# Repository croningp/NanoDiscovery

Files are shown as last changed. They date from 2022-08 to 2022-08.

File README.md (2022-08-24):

# Autonomous Intelligent Exploration, DIScovery and Optimisation of Nanomaterials (AI-EDISON)
Software and hardware control of AI-EDISON. The version-specific repository for the paper is available in Zenodo [here](https://zenodo.org/record/6654585). From that version, this repository has been updated from three perspectives below, but no relevant codes/files used in the work have been changed:

1. We corrected some typo errors and updated multiple README.md files as well as statements of license/restrictions for a clearer guidance; 
2. We have added some additional contents which include: a missing [license](Experiments/Software/modularwheelplatform/modularwheel/drivers/pH/DrDAQ/LICENSE.md) of DrDAQ driver locally to this repository (the preivous hyperlink was not valid); the [source codes](Theory/Optimization_targets) to simulate the target spectra for the experimental optimization in the paper.
3. We updated several unused/invalid links, scripts and functions (e.g., several links in [requirement.txt](Experiments/Software/modularwheelplatform/requirements.txt) and the "dense_to_sparse" function (which contains a variable error but was never used) in [dda.py](Theory/PyDScat-GPU/dda.py)) to avoid potential ambiguity.

**Please refer to this repository for general guidance and license information.**


## Experiment

### Hardware construction
The full bill of materials to construct the robot are available [here](Experiments/Hardware).
### Software control requirement
The following software are required to control the robot:
* Python >= 3.6 ([Linux](http://docs.python-guide.org/en/latest/starting/install3/linux/) / [Windows](https://www.python.org/downloads/release/python-363/))
* [Arduino Command Handler](https://github.com/croningp/Arduino-CommandHandler)
* [Arduino Command Tools](https://github.com/croningp/Arduino-CommandTools)
* [pySerial 3.4](https://github.com/pyserial/pyserial/)
* [SerialLabware](https://www.science.org/doi/10.1126/science.abo0058)
* [pycont](https://github.com/croningp/pycont)
* [commanduino](https://github.com/croningp/commanduino)
* [CommanduinoLabware](https://www.science.org/doi/10.1126/science.abo0058)
* [InorganicClusterDiscovery](https://github.com/croningp/InorganicClusterDiscovery)
* [XDL](https://croningroup.gitlab.io/chemputer/xdl/standard/index.html) (with its gitlab link [here](https://gitlab.com/croningroup/chemputer/xdl)) (Note we used XDL 1 in this work. Specifically, [XDL 1.6.0](https://gitlab.com/croningroup/chemputer/xdl/-/tree/v1.6.0) was used to generate the digital signatures of the six AuNPs.)
* [SeaBreeze](https://python-seabreeze.readthedocs.io/en/latest/)
* [PicoTech](https://github.com/picotech/picosdk-python-wrappers)
* [ModularWheelPlatform](Experiments/Software/modularwheelplatform)
* [Nanobot](Experiments/Software/Nanobot)

Go to the corresponidng folders of [ModularWheelPlatform](Experiments/Software/modularwheelplatform) and [Nanobot](Experiments/Software/Nanobot), and use "pip install ." to install these two packages. In ModularWheelPlatform, we used [DrDAQ](https://www.picotech.com/data-logger/drdaq/overview) to measure the pH. In Nanobot, the code is based on [SeaBreeze](https://python-seabreeze.readthedocs.io/en/latest/) from Ocean Optics to control the spectrometers. For the usage of UV-Vis spectrum, the integration time is set (either 0.01 or 0.02 s) to avoid spectral saturation.

<!-- ### Python library -->
<!-- To install all required Python libraries, run the following command: `pip install -r requirements.txt` -->
### Exploration with MAP-Elites
The MAP-Elites algorithm was described in the manuscript and supplementary information. An example of exploring the multiple-peak systems in chemical sapce 2 with pH control is available [here](Experiments/Software).
<!-- ### Optimisation with GS-LS 
The GS-LS algorithm was described in the manuscript and supplementary information. An example of optimizing towards a target spectrum of nanorods is [here](Experiments/Software). -->
### Simulating the target spectra for experimental optimisation
The original codes to simulate the target spectra for Au nanorods/octahedra for the experimental optimisation are [here](Theory/Optimization_targets). See below for more information about the simulation engine PyDScat-GPU.
### Multistep synthesis with directed graph structure
The codes to generate syntehsis/reaction/hardware graph, and control the robot are available [here](Experiments/Graph_Structure).
### The unique digital signatures of the synthesised nanoparticles
The codes to generate the unique digital signatures using XDL are available [here](Experiments/Hash_XDL).
## Theory
### Software requirement
* Python >= 3.6 ([Linux](http://docs.python-guide.org/en/latest/starting/install3/linux/) / [Windows](https://www.python.org/downloads/release/python-363/))
* [numpy](https://numpy.org/)
* [matplotlib](https://matplotlib.org/)
* [Tensorflow >= 2.0](https://www.tensorflow.org/)
* [pathlib](https://docs.python.org/3/library/pathlib.html)
* [fresnel](https://fresnel.readthedocs.io/en/stable/)
* [Mathematica >= 12.0](https://www.wolfram.com/mathematica/)
### PyDScat-GPU
PyDScat-GPU is developed for efficient scaterring simulations with [discrete-dipole approximation](https://en.wikipedia.org/wiki/Discrete_dipole_approximation) method. One example was given below, and see [here](Theory/PyDScat-GPU/) for more details and examples. 
#### Example code
```python
import os
import json
import pathlib
import numpy as np
from dda import DDA

# GPU Device Config
os.environ["CUDA_DEVICE_ORDER"]="PCI_BUS_ID"   
os.environ["CUDA_VISIBLE_DEVICES"]="3"

current_folder_path = pathlib.Path().absolute()

config = {'gpu_device': '/GPU:0',
          'dipole_length': 1,
          'min_wavelength': 0.4,
          'max_wavelength': 0.8,
          'num_wavelengths': 41,
          'ref_medium': 1.333,
          'rotation_steps': 10,
          'folder_path': None,
          'calculate_electricField': True,
          'lattice_constant': 0.41,
          'ref_data': [str(current_folder_path) + '/Au_ref_index.csv',str(current_folder_path) + '/Ag_ref_index.csv'],
          'metals': ["Au","Ag"],
          'dipole_data': str(current_folder_path)+ '/dipole_list.csv',
          "ratio":[1.0, 0.0],
          "method":"homo",
          "custom_ratio_path":None,
          'atom_data':None,
          'lattice_constant': None
        }
config['folder_path'] = str(current_folder_path)
np_dda = DDA(config)
np_dda.run_DDA()
np_dda.plot_spectra()
np.savetxt("Results.csv",np.array(np_dda.C_cross_total)/np.pi/np_dda.c_rad**2,delimiter=",")
```
### Benchmark of MAP-Elites and GS-LS
Both MAP-Elites and GS-LS algorithms were benchmarked in a simulated chemical space using [superellipsoid](https://en.wikipedia.org/wiki/Superellipsoid) as the shape descriptor. The code of creating the discrete dipoe representation of a superellipsoid is [here](Theory/Superellipsoid). We created the set of dipoles by changing the (a,b,c,r,t) parameters of the createDipoles function in the [mathematica notebook](Theory/Superellipsoid/Superellipsoid_Generate_Dipoles.nb) to approximate the specific geometry. 
#### *In silico* exploration using MAP-Elites
The codes to reproduce the results from the in silico exploration of two simulated chemical spaces are [here](Theory/Algorithms). 
#### *In silico* optimisation using GS-LS
The code to reproduce the results from the in silico optimisation is [here](Theory/Algorithms/Simulated_Space_2/1-GS-LS).

## License
The [license](LICENSE) aims to protect the design of the robot in this work for non-commercial usage only. For the codes used in this work, see [here](http://www.chem.gla.ac.uk/cronin/media/license/) for the license information. However, if the licenses listed here are incompatible with the licenses of certain resources that parts of this work are based on, the original licenses of these resources should be used for the relevant parts of this work.

Copyright 2022 The Cronin Group, University of Glasgow.

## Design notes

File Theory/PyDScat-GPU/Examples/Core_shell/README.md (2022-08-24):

dipole_list.csv (name changed), atomList_Octahedron.csv and coordNumList_Octahedron.csv are generated through Nanoparticle_Generator.nb. 
They represent the atomic model for FCC octahedron with an edge length of 20 nm and lattice constant of 0.41 nm.
Then we generated a core-shell structure by setting all the atoms as Ag first, and then change the atoms in the core to be Au later.

The atomic model for the Au core is generated by Nanoparticle_Generator_core.nb for exp1 to exp6, with the edge length from 20 nm to 10 nm.
The lattice constant is consistent with the one above (0.41 nm) and the edge length interval is 2 nm from exp1 to exp6.

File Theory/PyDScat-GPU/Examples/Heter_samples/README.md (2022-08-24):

The dipole list and atomic model are generated with mathematica. It's 20 nm(edge length) octahedron with FCC structure. The lattice constant is 0.41 nm. The file name of dipole set is changed (after created origially) for the DDA simulation.

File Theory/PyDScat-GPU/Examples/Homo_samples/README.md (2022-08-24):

The dipole list and atomic model are generated with mathematica. It's 20 nm(edge length) octahedron with FCC structure. The lattice constant is 0.41 nm. The file name of dipole set is changed (after created origially) for the DDA simulation. The atomic model is not really used in this example so are deleted in this batch of experiments.

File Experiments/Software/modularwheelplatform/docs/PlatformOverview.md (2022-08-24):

# Platform
The following is a generalised guide on how to structure your project. The structure of a project follows a standard as set [here.](http://datalore.chem.gla.ac.uk/GAK/PlatformTemplate) This is a base template structure that can be added to/modified to fit your project's specific needs.

# Basic Platform Structure
platformstructure

# Requirements
* [Commanduino](https://github.com/croningp/commanduino)
* [Arduino Command Handler](https://github.com/croningp/Arduino-CommandHandler)
* [Arduino Command Tools](https://github.com/croningp/Arduino-CommandTools)
* [PyCont](https://github.com/croningp/pycont) (If using Tricontinent Pumps)

# Project Folder
Holds all the information necessary to run the platform. It is split into two main folders: **Hardware** and **Software**

## **Hardware**
Holds all the files necessary for the building of this platform. Here, you can add STL files for 3D printed parts, links to building materials such as cross-beams, motors, Arduino kits, etc., amongst other items necessary for the construction of your platform. This repository comes fully equipped with all the 3D files necessary for construction and links to purchasing said building materials.

## **Software** 
Holds all the software necessary for operating your platform. A hierarchial structure is adopted here to maximise modularity, allowing additional modules to be introduced/removed as and when required. Firmware and Utilities folders should also be included to hold the Arduino code and general purpose fuctions respectively. The project structure is as follows:
```
Base Layer -> Operational Layer -> Managerial Layer
```
## Base Layer
This is the lowest level of the platform which implements the base functionality of the platform. That being, no specific operations would be conducted in these scripts, just basic setup and low-level functions. Examples would be setting up Tricont pumps, initialising a UV spectrometer or pH probe, setting up a camera, etc. See examples below:

### **PyCont Pump Base Layer**
This script simply sets up the Tricont pump controller using PyCont and sets all pumps to 0. The controller can then be called upon from an Operations script to give access to the pumps.  
For more information on PyCont, click [here](https://github.com/croningp/pycont).
```python
# Base Layer: PUMPS

import os
import inspect
import logging
import json

logging.basicConfig(level=logging.INFO)

HERE = os.path.dirname(os.path.abspath(inspect.getfile(inspect.currentframe())))
from pycont.controller import MultiPumpController

config_path = os.path.join(HERE, "pycont_config.json")
controller = MultiPumpController.from_configfle(config_path)

with open(config_path) as f:
    config = json.load(f)

controller.smart_initialize()

pumps = controller.get_pumps(controller.pumps)
for pump in pumps:
    pump.go_to_volume(0)
```

### **Commanduino Device Base Layer**
This script sets up Commanduino for any Arduino device, allowing you to access any device currently attached to it that is listed in its commanduino config file (operations/configs folder).  
For more information on how to use Commanduino, click [here](https://github.com/croningp/commanduino).
```python
import os
import sys
import json
import time
import inspect

from commanduino import CommandManager

HERE = os.path.dirname(os.path.abspath(inspect.getfile(inspect.currentframe())))

root_path = os.path.join(HERE, "..")
sys.path.append(root_path)

from utils import json_utils

""" CONSTANTS """
DEVICES = "devices"

class CoreDevice(object):
    """
    Class representing a core Commanduino system.
    Allows access to the modules attached

    Args:
        config (str): path to the Commanduino config file
    """
    def __init__(self, config):
        self.mgr = CommandManager.from_configfile(config)
        self.config = json_utils.read_json(config)

    def valid_device(self, dev_name):
        """
        Checks if the given device name is present within the config

        Args:
            dev_name (str): name of the device
        
        Returns:
            valid (bool): If the device is present or not
        """
        return dev_name in self.config[DEVICES].keys()

    def get_device_attribute(self, dev_name):
        """
        Gets the device attribute from CommandManager

        Args:
            dev_name (str): Name of the device

        Returns:
            device (CommandDevice): Device instance in the CommandManager

        Raises:
            AttributeError: The device is not in the CommandManager
        """
        if self.valid_device(dev_name):
            try:
                return getattr(self.mgr, dev_name)
            except AttributeError:
                print("No device named {0} in the manager!\nBailing out!".format(dev_name))
                sys.exit(-1)
        else:
            print("Invalid device name: {0}".format(dev_name))
            sys.exit(-1)

```

## Operational Layer
The operational layer is responsible for implementing all the functions specific to your platform. This takes a base layer component and adds a control script on top, allowing access to the hardware to perform the desired function.  
An example would be setting up a cleaning routine for pumps, dispensing reagents from pumps, turning the Geneva Wheel, raising and lowering modular drivers on the wheel etc.  
See below:

### **Example: Geneva Wheel Control Operations**
This example highlights using the Commanduino Core Base Layer and incorporating it into an operational layer control script for a Geneva Wheel. By using the base layer methods, we can get access to all the devices attached and write functions to perform specific tasks. In this case, turning the wheel, moving modular drivers and runing peristaltic pumps.
```python
import os
import sys
import time
import inspect

HERE = os.path.dirname(os.path.abspath(inspect.getfile(inspect.currentframe())))
root_path = os.path.join(HERE, "..")
sys.path.append(root_path)

from base_layer.commanduino_setup.core_device import CoreDevice

""" CONSTANTS """
WHEEL_NAME = "wheel"
FULL_WHEEL_TURN = 6400
PUMP_INCREMENT = 8000
MODULE_LOWER = -39000

class WheelControl(CoreDevice):
    """
    Class for controlling a Geneva Wheel system
    Contains methods for rotation, modular drivers, pumps, etc.
    Assumes the user has at least one Geneva wheel, one modular driver, and one peristaltic
    pump attached to their rig.

    Inherits:
        CoreDevice: Base Commanduino Device

    Args:
        config (str): Path to the config
    """
    def __init__(self, config):
        super().__init__(self, config)

    def turn_wheel(self, n_turns, wait=True):
        """
        Turns the Geneva Wheel n_turns times

        Args:
            n_turns (int): Number of turns
        """
        drive_wheel = self.get_device_attribute(WHEEL_NAME)
        for _ in range(n_turns):
            drive_wheel.move(FULL_WHEEL_TURN, wait=wait)

    def move_module(self, mod_name, pos, wait=True):
        """
        Moves the modular driver to a set position

        Args:
            mod_name (str): Name of the module
            pos (int/float): Number of steps to move
            wait (bool): Wait for the device to be idle, default set to True
        """
        module = self.get_device_attribute(mod_name)
        module.move(-pos, wait=wait) # -ve due to inverted direction

    def lower_module(self, mod_name, wait=True):
        """
        Lowers the modular driver

        Args:
            mod_name (str): Name of the modular driver
            wait (bool): Wait for the device to be idle, default set to true
        """
        self.move_module(mod_name, MODULE_LOWER, wait=wait)

    def home_module(self, mod_name, wait=True):
        """
        Brings the module back to its home position

        Args:
            mod_name (str): Name of the module
            wait (bool): Wait for the device to be idle, default set to true
        """
        module = self.get_device_attribute(mod_name)
        module.home(wait=wait)

    def run_peri_pump(self, pump_name, num_secs):
        """
        Runs a peristaltic pump for num_secs time

        Args:
            pump_name (str): Name of the pump
            num_secs (int/float): Number of seconds to run for
        """
        pump = self.get_device_attribute(pump_name)
        curr_time = time.time()
        while time.time() < (curr_time + num_secs):
            pump.move(PUMP_INCREMENT)    

```

## Managerial Layer
The Managerial Layer is responsible for consolidating all required operational layer modules into a single, easily accessible script. This script can then be called by an experimental run script to give you access to all the functions.  
By doing so, wrapper functions can be implemented that encompass an entire operation e.g. cleaning. Other manager functions can also be implemented. Example function below:
```python
# manager.py
def clean_routine(self):
    self.wheel_control.lower_module()
    self.pump_control.empty_vessel()
    self.pump_control.clean()
    self.wheel_control.home_module()
    self.wheel_control.turn_wheel()
```
Skeletal example of a manager.py file:
```python
import os
import sys
import inspect

HERE = os.path.dirname(os.path.abspath(inspect.getfile(inspect.currentframe())))
root_path = os.path.join(HERE, "..")
sys.path.append(root_path)

""" Operations Modules """
from operations.tricont_control import TricontControl
from operations.wheel_control import WheelControl
# Add more as required

class Manager(object):
    """
    Class representing a manager which governs the entire platform
    Wrapper around certain operations for the platform and general management
    """
    def __init__(self):
        self.pump_control = TricontControl()
        self.wheel_control = WheelControl()
        # Add more as required

    """
    Add general managerial functions here 
    """

    """
    Add wrappers to operational functions here
    """

```

## Firmware
The firmware folder is where all Arduino and microcontroller code should be stored. For Arduino code to be used with Commanduino, please see the [Arduino Command Handler](https://github.com/croningp/Arduino-CommandHandler) and [Arduino Command Tools](https://github.com/croningp/Arduino-CommandTools) repositories for installation instructions and demos.

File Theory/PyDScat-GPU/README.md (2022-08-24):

# Config file for PyDScat-GPU simulation
The major part was written in Python. The config file defines the necessary information for simulation. There're several parameters in the config file (a dictionary and usually stored as a json file) and see the information below for different parameters:
1. 'gpu_device': '/GPU:0',
- defines the GPU device to be used
2. 'dipole_length': 1,
- defines the length of dipole in nanometer
3. 'min_wavelength': 0.4, 
- defines the lowest wavelength for spectrum in micrometer
4. 'max_wavelength': 0.8, 
- defines the highest wavelength for spectrum in micrometer
5. 'num_wavelengths': 41, 
- defines the number of linear interval between lowest and highest wavelength
6. 'ref_medium': 1.333, 
- defines the medium of the simulation
7. 'rotation_steps': 10, 
- defines the average number of orientations for every solid angle
8. 'folder_path': None, 
- defines the folder path where we store the data (still in test so some data may store in the current folder)
9. 'calculate_electricField': False, 
- defines if we will calculate the local electric field
10. 'metals': ["Au","Ag"], 
- defines the metallic components in the nanoparticles
11. 'ref_data': [str(current_folder_path) + '/Au_ref_index.csv',str(current_folder_path) + '/Ag_ref_index.csv'],
-  defines the refractive index for components respectively. Keep the sequence of paths consistent with those in metals.
12. 'dipole_data': str(current_folder_path)+'/Core_shell' + '/dipole_list.csv',
- defines the position of dipoles. Always integer. 
13. "method":"heter_atomic",
- defines the method for the simulation. It can be "homo", "heter_atomic" or "heter_custom"
14. "ratio":None,
- has to be defined for method "homo", else not required. A list object recording the percentages of different components of the homogenous nanoparticle. The summation should be 1. 
15. "custom_ratio_path":None
- has to be defined for method "heter_custom", else not required. Path to the csv file storing the custom component percentages for dipoles. After reading in the csv file, we should have a n by N array, where n is the metallic component number and N is the dipole number.
16. 'atom_data': str(current_folder_path)+'/Core_shell' + exp_index + '/atomList_Octahedron.csv',
- has to be defined for method "heter_atomic", else not required. It defines the path for the positions of atoms. Always normarlized to lattice unit. 
17. 'lattice_constant': 0.41
- has to be defined for method "heter_atomic", else not required. It defines the lattice constant for an atomic model

[Mathematica >= 12.0](https://www.wolfram.com/mathematica/) was used to generate dipoles or create meshes to calculate the electric field distribution if 'calculate_electricField' is True. For this calculation, the dipole length and the lattice constant should be set in [NanoparticleProperties.wl](NanoparticleProperties.wl) accordingly. The path in [dipole_analysis.wls](dipole_analysis.wls) should be changed accordingly to load the package.

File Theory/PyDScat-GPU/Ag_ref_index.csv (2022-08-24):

Wavelength, µm | real | image
0.1879 | 1.07 | 1.212
0.1916 | 1.1 | 1.232
0.1953 | 1.12 | 1.255
0.1993 | 1.14 | 1.277
0.2033 | 1.15 | 1.296
0.2073 | 1.18 | 1.312
0.2119 | 1.2 | 1.325
0.2164 | 1.22 | 1.336
0.2214 | 1.25 | 1.342
0.2262 | 1.26 | 1.344
0.2313 | 1.28 | 1.357
0.2371 | 1.28 | 1.367
0.2426 | 1.3 | 1.378
0.249 | 1.31 | 1.389
0.2551 | 1.33 | 1.393
0.2616 | 1.35 | 1.387
0.2689 | 1.38 | 1.372
0.2761 | 1.41 | 1.331
0.2844 | 1.41 | 1.264
0.2924 | 1.39 | 1.161
0.3009 | 1.34 | 0.964
0.3107 | 1.13 | 0.616
0.3204 | 0.81 | 0.392
0.3315 | 0.17 | 0.829
0.3425 | 0.14 | 1.142
0.3542 | 0.1 | 1.419
0.3679 | 0.07 | 1.657
0.3815 | 0.05 | 1.864
0.3974 | 0.05 | 2.07
0.4133 | 0.05 | 2.275
0.4305 | 0.04 | 2.462
0.4509 | 0.04 | 2.657
0.4714 | 0.05 | 2.869
0.4959 | 0.05 | 3.093
0.5209 | 0.05 | 3.324
0.5486 | 0.06 | 3.586
0.5821 | 0.05 | 3.858
0.6168 | 0.06 | 4.152
0.6595 | 0.05 | 4.483
0.7045 | 0.04 | 4.838
0.756 | 0.03 | 5.242
0.8211 | 0.04 | 5.727
0.892 | 0.04 | 6.312
0.984 | 0.04 | 6.992
1.088 | 0.04 | 7.795
1.216 | 0.09 | 8.828
1.393 | 0.13 | 10.1
1.61 | 0.15 | 11.85
1.937 | 0.24 | 14.08

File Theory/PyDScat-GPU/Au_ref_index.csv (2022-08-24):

Wavelength, µm | real | image
0.1879 | 1.28 | 1.188
0.1916 | 1.32 | 1.203
0.1953 | 1.34 | 1.226
0.1993 | 1.33 | 1.251
0.2033 | 1.33 | 1.277
0.2073 | 1.3 | 1.304
0.2119 | 1.3 | 1.35
0.2164 | 1.3 | 1.387
0.2214 | 1.3 | 1.427
0.2262 | 1.31 | 1.46
0.2313 | 1.3 | 1.497
0.2371 | 1.32 | 1.536
0.2426 | 1.32 | 1.577
0.249 | 1.33 | 1.631
0.2551 | 1.33 | 1.688
0.2616 | 1.35 | 1.749
0.2689 | 1.38 | 1.803
0.2761 | 1.43 | 1.847
0.2844 | 1.47 | 1.869
0.2924 | 1.49 | 1.878
0.3009 | 1.53 | 1.889
0.3107 | 1.53 | 1.893
0.3204 | 1.54 | 1.898
0.3315 | 1.48 | 1.883
0.3425 | 1.48 | 1.871
0.3542 | 1.5 | 1.866
0.3679 | 1.48 | 1.895
0.3815 | 1.46 | 1.933
0.3974 | 1.47 | 1.952
0.4133 | 1.46 | 1.958
0.4305 | 1.45 | 1.948
0.4509 | 1.38 | 1.914
0.4714 | 1.31 | 1.849
0.4959 | 1.04 | 1.833
0.5209 | 0.62 | 2.081
0.5486 | 0.43 | 2.455
0.5821 | 0.29 | 2.863
0.6168 | 0.21 | 3.272
0.6595 | 0.14 | 3.697
0.7045 | 0.13 | 4.103
0.756 | 0.14 | 4.542
0.8211 | 0.16 | 5.083
0.892 | 0.17 | 5.663
0.984 | 0.22 | 6.35
1.088 | 0.27 | 7.15
1.216 | 0.35 | 8.145
1.393 | 0.43 | 9.519
1.61 | 0.56 | 11.21
1.937 | 0.92 | 13.78

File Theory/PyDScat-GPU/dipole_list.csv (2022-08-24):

-1.399999999999999467e+01 | 0.000000000000000000e+00 | 0.000000000000000000e+00
-1.299999999999999822e+01 | -9.999999999999964473e-01 | 0.000000000000000000e+00
-1.299999999999999822e+01 | 0.000000000000000000e+00 | -9.999999999999964473e-01
-1.299999999999999822e+01 | 0.000000000000000000e+00 | 0.000000000000000000e+00
-1.299999999999999822e+01 | 0.000000000000000000e+00 | 1.000000000000005329e+00
-1.299999999999999822e+01 | 1.000000000000005329e+00 | 0.000000000000000000e+00
-1.199999999999999289e+01 | -1.999999999999992895e+00 | 0.000000000000000000e+00
-1.199999999999999289e+01 | -9.999999999999964473e-01 | -9.999999999999964473e-01
-1.199999999999999289e+01 | -9.999999999999964473e-01 | 0.000000000000000000e+00
-1.199999999999999289e+01 | -9.999999999999964473e-01 | 1.000000000000005329e+00
-1.199999999999999289e+01 | 0.000000000000000000e+00 | -1.999999999999992895e+00
-1.199999999999999289e+01 | 0.000000000000000000e+00 | -9.999999999999964473e-01
-1.199999999999999289e+01 | 0.000000000000000000e+00 | 0.000000000000000000e+00
-1.199999999999999289e+01 | 0.000000000000000000e+00 | 1.000000000000005329e+00
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

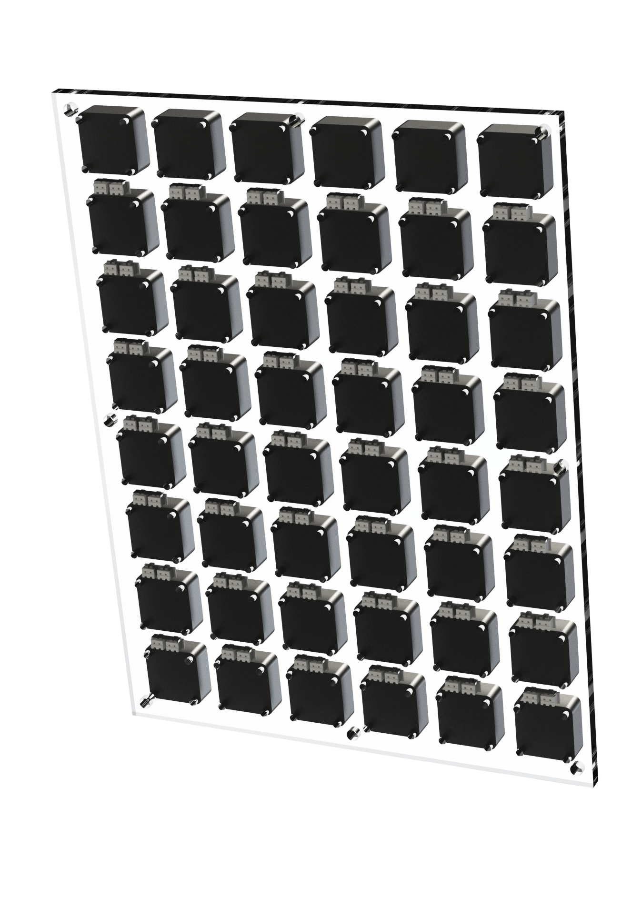
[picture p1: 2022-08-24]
Experiments/Software/modularwheelplatform/docs/hardware/StirringRingPCB/renders/plate_bottom_view.png

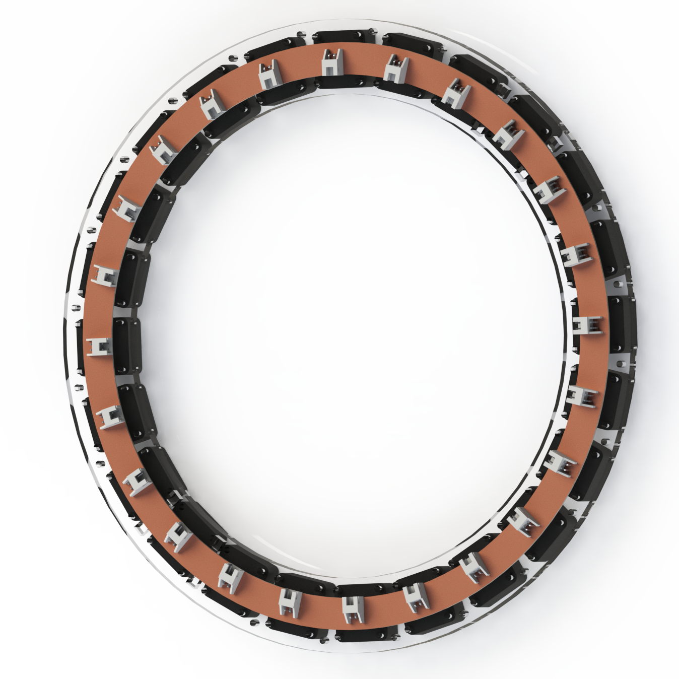
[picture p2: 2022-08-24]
Experiments/Software/modularwheelplatform/docs/hardware/StirringRingPCB/renders/ring_bottom_view.png

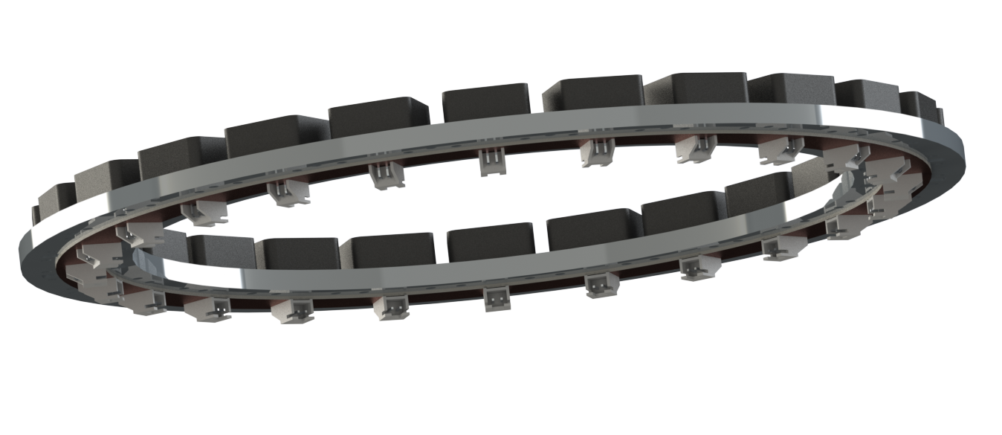
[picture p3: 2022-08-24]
Experiments/Software/modularwheelplatform/docs/hardware/StirringRingPCB/renders/ring_side_view.png

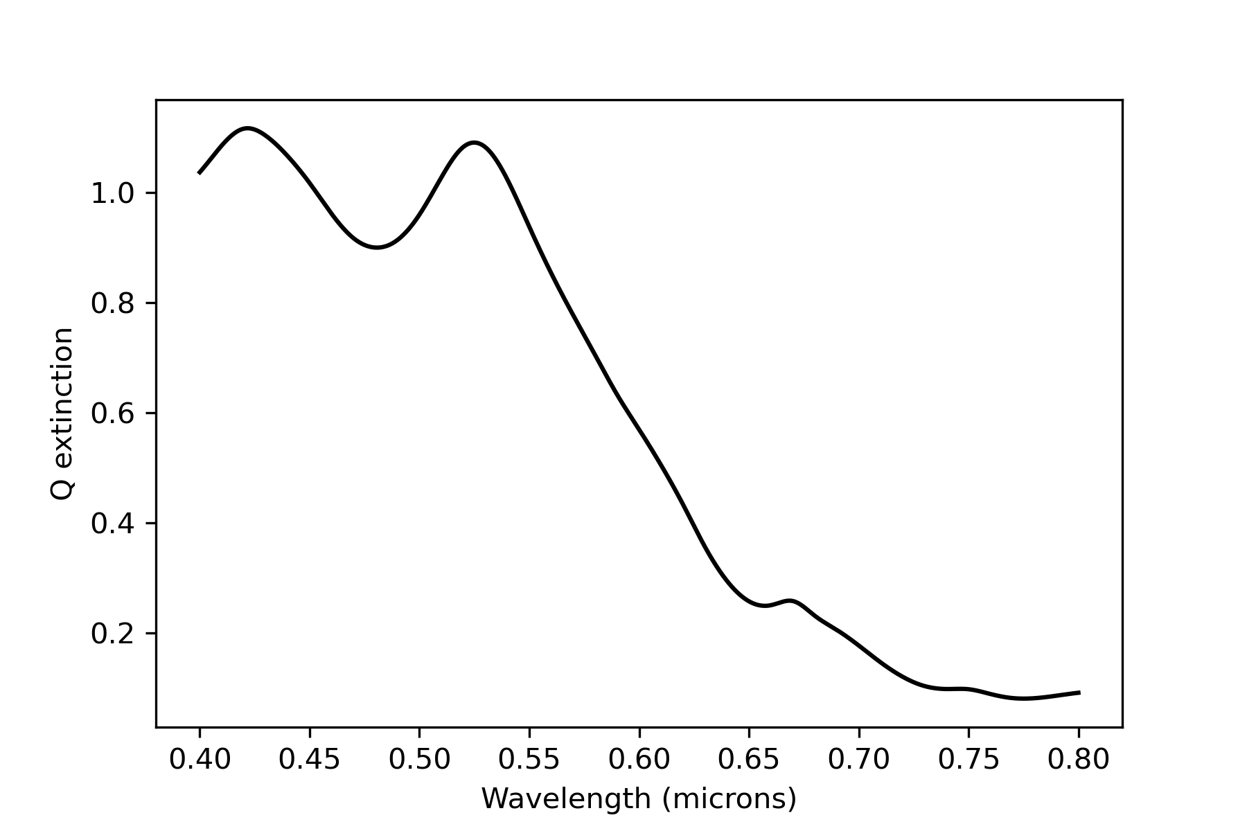
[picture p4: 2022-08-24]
Theory/PyDScat-GPU/Examples/Core_shell/exp2/UV_Vis.png

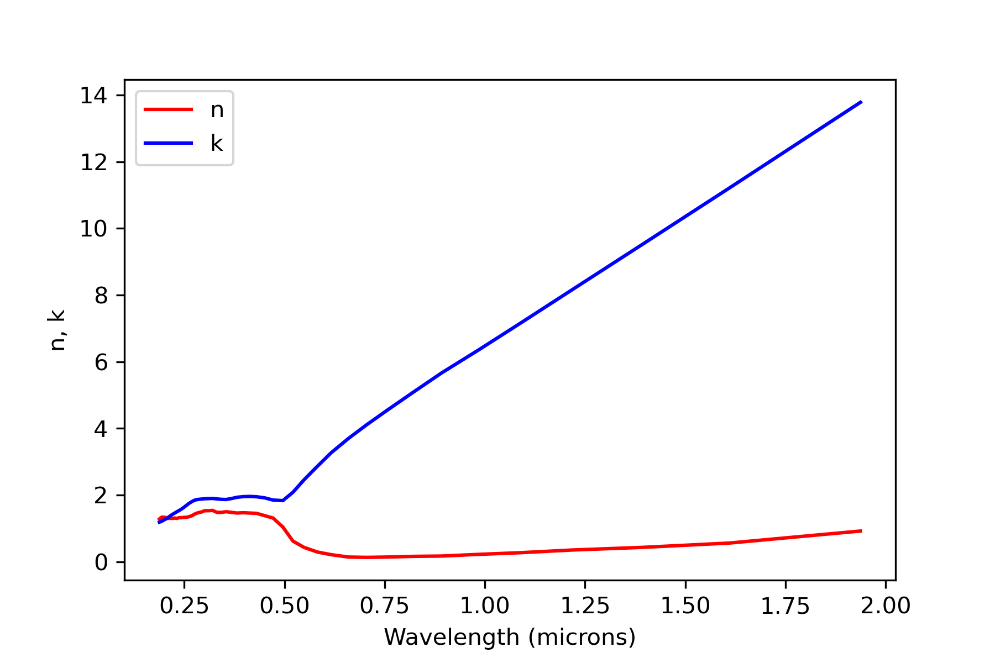
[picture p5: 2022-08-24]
Theory/PyDScat-GPU/Examples/Core_shell/exp5/Au_ref_index.png

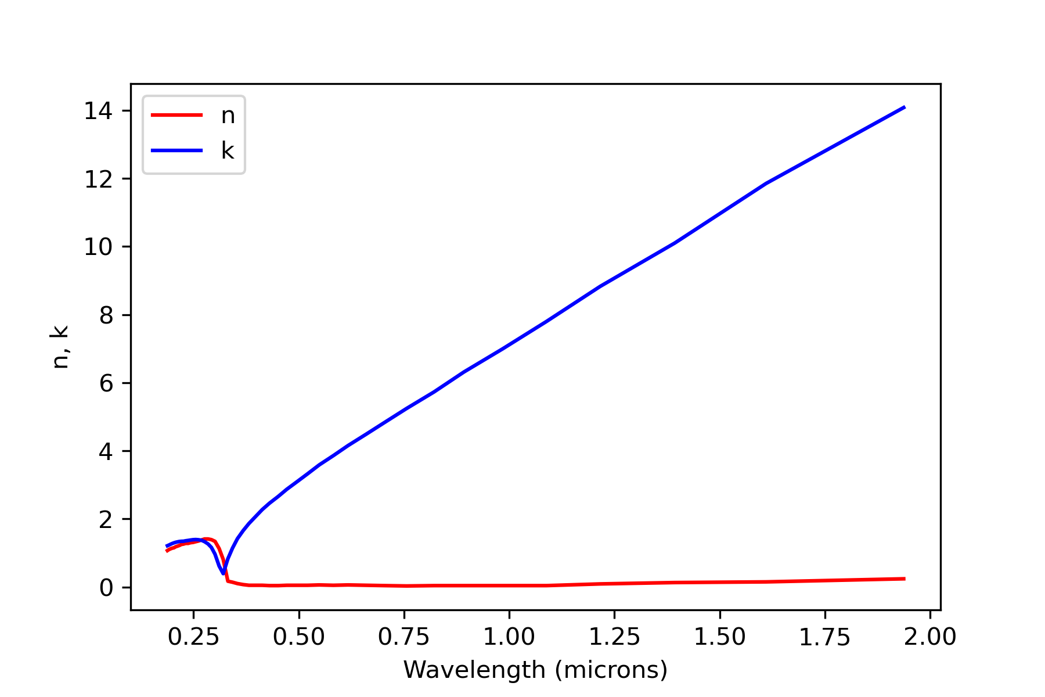
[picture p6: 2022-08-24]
Theory/PyDScat-GPU/Examples/Heter_samples/exp3/Ag_ref_index.png

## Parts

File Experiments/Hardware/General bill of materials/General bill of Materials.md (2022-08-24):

# Bill of Materials

This page contains a brief description of and links for the commercially available parts needed to construct this platform   

# Base components for chemical reaction module

* Structural: V-slot aluminium [profile](http://ooznest.co.uk/V-Slot/Linear-Rails/V-Slot-Linear-Rail-2020mm):
  - 310 mm x 4
  - 350 mm x 4
  - 135 mm x 4
* Structural: 60 (each) M5 x 8mm and 6mm [screws](http://ooznest.co.uk/Low-Profile-M5-Bolts?search=M5) with accompanying 120 [drop-in tee nuts](http://ooznest.co.uk/Drop-In-Tee-Nuts?search=drop) you will have spares
* Structural: 16 x Universal (single) L-[bracket](http://ooznest.co.uk/V-Slot/Brackets/Universal-L-Brackets)
* Structural: [Acrylic](http://www.acrylic-online.co.uk/) sheets 4mm and 6 mm (600 x 500mm minimum) x 1
* Structural: Assorted 3D printed [parts](https://github.com/croningp/NanomatDiscovery/tree/master/Experiments/Hardware/Modular%20wheel/Prints)
* Structural: Assorted M3 x 12/16/20/30mm [screws](https://www.accu.co.uk/en/64-low-head-cap-screws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) and [nuts](https://www.accu.co.uk/en/44-thin-hexagon-nuts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)
* Structural: Slot [cover](https://ooznest.co.uk/product/slot-cover/) for organising cables and tubes
* Electronic: Arduino mega 2560 and [RAMPS](https://ooznest.co.uk/product/ramps-14-controller-board/) 1.4 with a [DRV8825](https://ooznest.co.uk/product/drv8825-stepper-motor-driver/) driver for each motor you intend to use. The options for the Arduino is included in the drop down menu options x 1
* Electronic: 25 x 25 x 10 mm DC [fans](http://ooznest.co.uk/12V-DC-25mm-Fan?search=25mm). 24 for the platform stirring ring and 48 for the stirring mantle. For each fan you will need a JST housing pair, [male](https://uk.rs-online.com/web/p/pcb-headers/8201582/) and [female](https://uk.rs-online.com/web/p/pcb-connector-housings/8201611/), using these JST [crimps](https://uk.rs-online.com/web/p/pcb-connector-contacts/8201529) for powering the stirring fans.
* Electronic: Crimping [tool](https://www.crimpingtools.com/products/iwiss-xh2-54-3-96-ph2-0-px-kk254-jst-molex-dupont-d-sub-terminal-crimping-tool-sn-01bm-rachet-crimper-awg28-20-0-08-0-5mm) specific to the fan assemblies 
* Electronic: For simple electrical connections eg between the power supple and RAMPs board any crimp/ crimp housing conncetion can be used. We use simple Molex housings for crimps: [male](https://uk.rs-online.com/web/p/pcb-connector-housings/4841811/) and [female](https://uk.rs-online.com/web/p/pcb-connector-housings/4841748/) with accompanying crimps: [male](https://uk.rs-online.com/web/p/pcb-connector-contacts/6706316/) and [female](https://uk.rs-online.com/web/p/pcb-connector-contacts/6706307/)
* Electronic: Corsair SF450 [power supply](https://www.amazon.co.uk/Corsair-SF450-Fully-Modular-Supply/dp/B01CR5XJR6) x 1
* Electronic: Nema17 stepper x 1 [motor](https://www.omc-stepperonline.com/nema-17-bipolar-45ncm-64oz-in-2a-42x42x40mm-4-wires-w-1m-cable-and-connector.html) with accompanying Pololu aluminium mounting [hub](https://www.pololu.com/product/1998). This part joins the drive wheel to the stepper motor shaft x1
* Electronic: 4-wire Molex [female](https://uk.rs-online.com/web/p/pcb-connector-contacts/0467598/) crimps and [housings](https://uk.rs-online.com/web/p/pcb-connector-housings/6795375/) for Stepper motors, both pumps and drive wheel.  
* Electronic: Any 2 and 4 way crimp housings. It matters that the crimps match the plastic housings you chose, beyond that many types can be used.
* Electronic: Stepper motor to RAMP connection [housings](https://uk.rs-online.com/web/p/products/2964956/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) x 1 per stepper motor (use with appropriate crimps for this housing)
* Fan stirring [magnets](https://www.first4magnets.com/rectangular-magnets-c35/15-x-4-x-4mm-thick-n42-neodymium-magnet-2-2kg-pull-p3499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) x 30
* Stirring ring tripod [magnets](https://www.first4magnets.com/circular-disc-rod-c34/8mm-dia-x-2mm-thick-n42-neodymium-magnet-1kg-pull-p3010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|ps_1_16656)
* Driven wheel [bearing](https://uk.rs-online.com/web/p/ball-bearings/4420082/) x 1
* The modular wheel system construction information can be found [here](https://github.com/croningp/InorganicClusterDiscovery/tree/master/clusterbot/hardware/BuildInstructions)

# X/Y and Z motion modules

* NSK PU Series, P1U090095SKN-PCT, Linear Guide Rail 9mm width. [95mm](https://uk.rs-online.com/web/p/linear-guide-rails/6192391) for Z and [155mm](https://uk.rs-online.com/web/p/linear-guide-rails/6192408) for X/Y.
* NSK Linear Guide [Carriage](https://uk.rs-online.com/web/p/linear-guide-blocks/6192442) PAU09TRS, PU.
* Omron [microswitch](https://uk.farnell.com/omron-electronic-components/d2f01lt/microswitch-hinge-lever-0-1/dp/1961085) for positioning.
* For Z motion Nema11 external 34 mm stack [100 mm lead](https://www.omc-stepperonline.com/nema-11-external-34mm-stack-075a-lead-2mm007874-length-100mm-11ls13-0754e-100b.html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).
* For X/Y motion Nema11 external 32 mm stack [150 mm lead](https://www.omc-stepperonline.com/nema-11-external-32mm-stack-042a-lead-254mm01-length-150mm-11ls13-04243-150e.html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).

# Pumps/Liquid handling

  - C-series tricontinent 4-way valve [pumps](https://www.gardnerdenver.com/en-za/tricontinent/c-series-syringe-pumps) 
  - [1/8mm](https://kinesis.co.uk/tubing-tubing-ptfe-1-8-3-2mm-od-x-1-5mm-id-10m-008t32-150-10.html) OD PTFE tubing
  - [1/16mm](https://kinesis.co.uk/tubing-tubing-ptfe-1-16-1-6mm-od-x-0-8mm-id-20m-008t16-080-20.html) OD PTFE tubing
  - Idex flangeless fittings Nat PP [1/8](https://www.idex-hs.com/store/fluidics/fluidic-connections/fittings/flat-bottom-fittings/flangeless-fitting-natural-polypropylene-1-4-28-flat-bottom-for-1-8-od.html)
  - Idex flangeless fittings Nat PP [1/16](https://www.coleparmer.co.uk/i/idex-xp-245-flangeless-fitting-standard-knurl-natural-pfa-1-16-od-tubing-1-4-28-flat-bottom-1-ea/0202080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)

# Platform box

* Structural: V-slot 20 x20 aluminium [profile](http://ooznest.co.uk/V-Slot/Linear-Rails/V-Slot-Linear-Rail-2020mm) as above, built to the users constraints. The unit used in this work was 752 mm x 996 mm x 472 mm total including acrylic walls. The required:
    - 7 x 704 mm (depth)
    - 4 x 998 mm (width)
    - 5 x 424 mm (height)
* Structural: 8 x Acrylic sheet, 4 mm at 1000 mm x 600 mm (find local supplier)
* Stock solutions were all contained within the temperature controlled area, either on the floor or on internal shelves constructed from v-slot profile and acrylic securing holder.
* Stego fan [heater](https://uk.farnell.com/stego/02810-0-00/fan-heater-400w-t-safe-d-rail/dp/1870845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|pcrid|483687683200|plid||kword||match||slid||product|1870845|pgrid|112844087023|ptaid|pla-338451119240|&CMP=KNC-GUK-SHOPPING-SMEC-Whoops-Newstructure-Test737-Desktop-ME&gross_price=true)
* Temperature controller box:
    - Solid state [relay](https://uk.rs-online.com/web/p/solid-state-relays/0346895/)
    - K-type [thermocouples](https://uk.rs-online.com/web/p/thermocouples/1236311/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)
    - Lumel [PID](https://uk.rs-online.com/web/p/temperature-controllers/8947001/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) controller

# Spectroscopy set-up

* QEpro absorbance [spectrometer](https://www.oceaninsight.com/products/spectrometers/high-sensitivity/qepro-series/) configured 400-950 nm.
* Assorted fibre optic cables suited for our needs
* PEEK FIA-Z-SMA 905 [flow cell](https://www.flowinjection.com/hardware/flow-cells/sma-z-series) with 10 mm path length.
* DH-2000-S [light source](https://www.oceaninsight.com/products/light-sources/uv-vis-nir-light-sources/deuteriumhalogen/)

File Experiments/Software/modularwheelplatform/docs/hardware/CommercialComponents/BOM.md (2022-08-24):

# Bill of Materials

This page contains a brief description of and links for the commercially available parts needed to produce this platform   

# Wheel platform

* Structural: V-slot aluminium [profile](http://ooznest.co.uk/V-Slot/Linear-Rails/V-Slot-Linear-Rail-2020mm):
  - 310 mm x 4
  - 350 mm x 4
  - 135 mm x 4
* Structural: 60 (each) M5 x 8 and 6mm [screws](http://ooznest.co.uk/Low-Profile-M5-Bolts?search=M5) with accompanying 120 [drop-in tee nuts](http://ooznest.co.uk/Drop-In-Tee-Nuts?search=drop) you will have spares
* Structural: 16 x Universal (single) L-[bracket](http://ooznest.co.uk/V-Slot/Brackets/Universal-L-Brackets)
* Structural: [Acrylic](http://www.acrylic-online.co.uk/) sheets 4mm and 6 mm (600 x 500mm minimum) x 1
* Structural: Assorted 3D printed [parts](LINK TO STL FOLDER)
* Structural: Assorted M3 x 12/16/20/30mm [screws](https://www.accu.co.uk/en/64-low-head-cap-screws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) and [nuts](https://www.accu.co.uk/en/44-thin-hexagon-nuts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)
* Structural: Slot [cover](https://ooznest.co.uk/product/slot-cover/) for organising cables and tubes
* Electronic: Arduino mega 2560 and [RAMPS](https://ooznest.co.uk/product/ramps-14-controller-board/) 1.4 with a [DRV8825](https://ooznest.co.uk/product/drv8825-stepper-motor-driver/) driver for each motor you intend to use. The options for the Arduino is included in the drop down menu options x 1
* Electronic: 25 x 25 x 10 mm DC [fans](http://ooznest.co.uk/12V-DC-25mm-Fan?search=25mm). 24 for the platform stirring ring and 48 for the stirring mantle. For each fan you will need a JST housing pair, [male](https://uk.rs-online.com/web/p/pcb-headers/8201582/) and [female](https://uk.rs-online.com/web/p/pcb-connector-housings/8201611/), using these JST [crimps](https://uk.rs-online.com/web/p/pcb-connector-contacts/8201529) for powering the fans via the PCB [ring](LINK).
* Electronic: Crimping [tool](https://www.crimpingtools.com/products/iwiss-xh2-54-3-96-ph2-0-px-kk254-jst-molex-dupont-d-sub-terminal-crimping-tool-sn-01bm-rachet-crimper-awg28-20-0-08-0-5mm) specific to the fan assemblies 
* Electronic: For simple electrical connections eg between the power supple and RAMPs board any crimp/ crimp housing conncetion can be used. We use simple Molex housings for crimps: [male](https://uk.rs-online.com/web/p/pcb-connector-housings/4841811/) and [female](https://uk.rs-online.com/web/p/pcb-connector-housings/4841748/) with accompanying crimps: [male](https://uk.rs-online.com/web/p/pcb-connector-contacts/6706316/) and [female](https://uk.rs-online.com/web/p/pcb-connector-contacts/6706307/)
* Electronic: Corsair SF450 [power supply](https://www.amazon.co.uk/Corsair-SF450-Fully-Modular-Supply/dp/B01CR5XJR6) x 1
* Electronic: Nema17 stepper x 1 [motor](https://www.omc-stepperonline.com/nema-17-bipolar-45ncm-64oz-in-2a-42x42x40mm-4-wires-w-1m-cable-and-connector.html) with accompanying Pololu aluminium mounting [hub](https://www.pololu.com/product/1998) (this part joins the drive wheel to the stepper motor shaft) x1
* Electronic: 4-wire Molex [female](https://uk.rs-online.com/web/p/pcb-connector-contacts/0467598/) crimps and [housings](https://uk.rs-online.com/web/p/pcb-connector-housings/6795375/) for Stepper motors, both pumps and drive wheel.  
* Electronic: Any 2 and 4 way crimp housings. It matters that the crimps match the plastic housings you chose, beyond that many types can be used.
* Electronic: Stepper motor to RAMP connection [housings](https://uk.rs-online.com/web/p/products/2964956/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) x 1 per stepper motor (use with appropriate crimps for this housing)
* Pumps: Gardener denver SR10-30 series, 24V stepper motor driven peristaltic [pumps](https://www.gardnerdenver.com/en-us/thomas/peristaltic-liquid-pumps/sr-10-30-series)
* Pumps: Tubing and connectors from Kinesis/Cole-Palmer:
  - [1/8mm](https://kinesis.co.uk/tubing-tubing-ptfe-1-8-3-2mm-od-x-1-5mm-id-10m-008t32-150-10.html) OD PTFE tubing
  - [1/16mm](https://kinesis.co.uk/tubing-tubing-ptfe-1-16-1-6mm-od-x-0-8mm-id-20m-008t16-080-20.html) OD PTFE tubing
  - Idex flangeless fittings Nat PP [1/8](https://www.idex-hs.com/store/fluidics/fluidic-connections/fittings/flat-bottom-fittings/flangeless-fitting-natural-polypropylene-1-4-28-flat-bottom-for-1-8-od.html)
  - Idex flangeless fittings Nat PP [1/16](https://www.coleparmer.co.uk/i/idex-xp-245-flangeless-fitting-standard-knurl-natural-pfa-1-16-od-tubing-1-4-28-flat-bottom-1-ea/0202080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)
  - Idex 1/4-28 female to male [Luer](https://www.coleparmer.co.uk/i/idex-p-675-threaded-luer-adapter-red-etfe-natural-pp-0-050-bore-male-luer-lock-x-female-1-4-28-flat-bottom-1-ea/0201421) barbed luer fittings to suite the peristaltic pump tubing and the make fitting on these Idex 1/4-28 Luers. 
  - MasterFlex fittings, PP, straight female [Luer](https://www.coleparmer.co.uk/i/masterflex-fitting-polypropylene-straight-female-luer-to-hose-barb-adapter-3-32-25-pk/4550802) with barbed adaptor. Given the peristalitc pump tubing can differ in size based on the flow rate, you will need to buy these with the appropriately barded fitting to fit the tubing, this is the one we have used for 4 mL/min flow rate peri pump heads
  - PTFE lined precision dispensing needles 25 gauge TLC lined tip [needle](https://www.nordson.com/en/divisions/efd/products/dispense-tips/ptfe-lined-tips). 
* Fan stirring [magnets](https://www.first4magnets.com/rectangular-magnets-c35/15-x-4-x-4mm-thick-n42-neodymium-magnet-2-2kg-pull-p3499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) x 30
* Stirring ring tripod [magnets](https://www.first4magnets.com/circular-disc-rod-c34/8mm-dia-x-2mm-thick-n42-neodymium-magnet-1kg-pull-p3010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|ps_1_16656)
* Driven wheel [bearing](https://uk.rs-online.com/web/p/ball-bearings/4420082/) x 1
* Modular syringe driver. The components for this part and instructions for its assembly are found [here](https://github.com/croningp/ModularSyringeDriver)

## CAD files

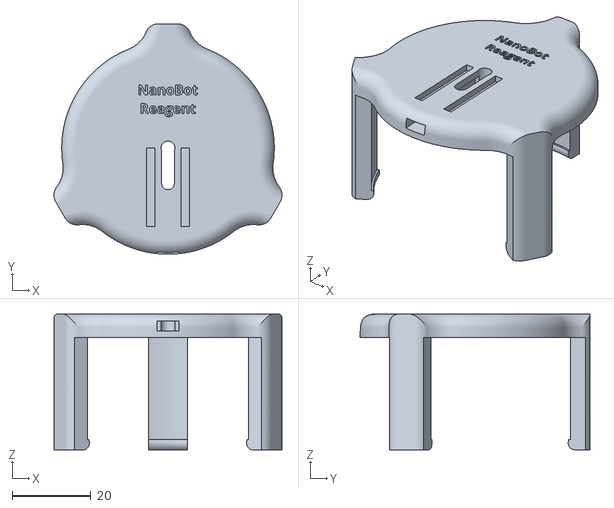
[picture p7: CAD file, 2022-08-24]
Experiments/Hardware/Quality of life/Stock bottle tube holders/Stock solution tube holder- Main body.stl
57.9 x 58.5 x 34.5

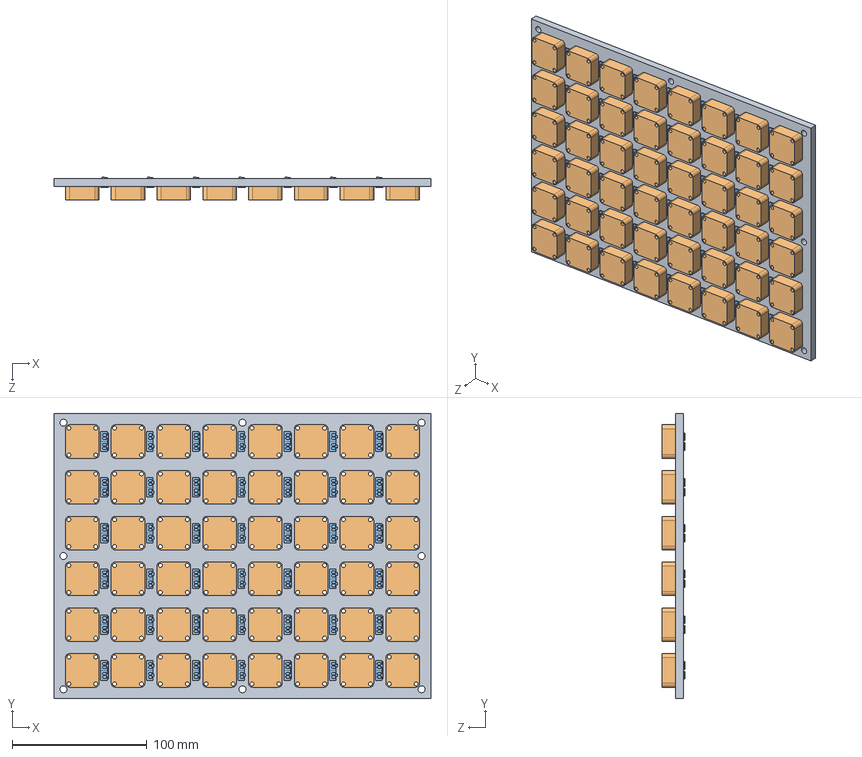
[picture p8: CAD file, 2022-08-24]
Experiments/Software/modularwheelplatform/docs/hardware/StirringRingPCB/plate_assembly.SLDASM
280.0 x 212.0 x 17.0 mm
plate
Fan x 48
XHP-2 x 84

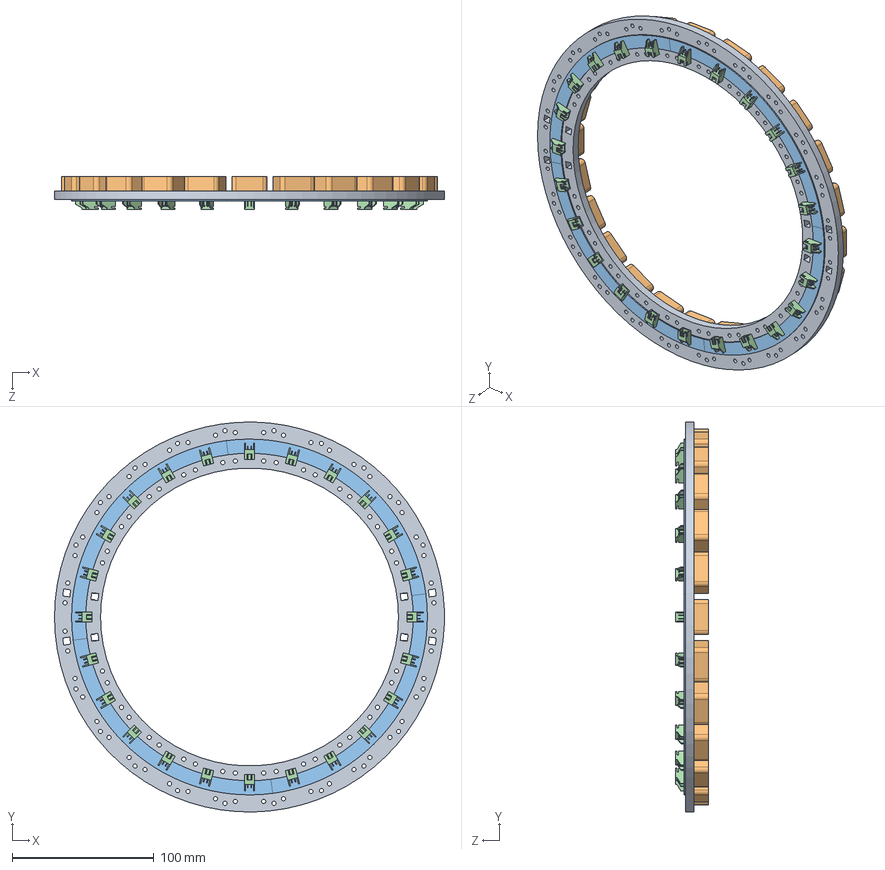
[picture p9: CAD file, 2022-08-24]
Experiments/Software/modularwheelplatform/docs/hardware/StirringRingPCB/ring_assembly.SLDASM
275.0 x 274.9 x 23.0 mm
ring
Fan x 24
Board^ring_assembly x 4
S2B-XH-A x 24

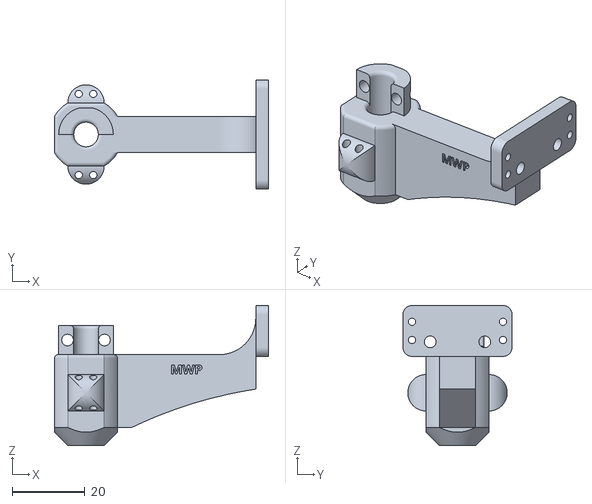
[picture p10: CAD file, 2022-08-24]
Experiments/Hardware/CRM advanced modules/Prints/pH module/MSD- Long reach probe mount - Probe holder.stl
58.8 x 30.0 x 38.5

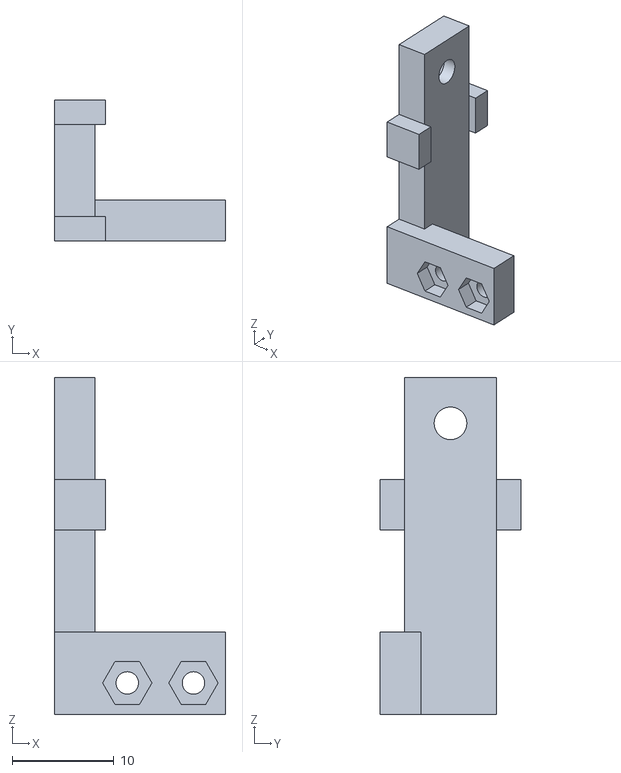
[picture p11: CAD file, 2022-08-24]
Experiments/Hardware/CRM advanced modules/Prints/Sample extraction analysis/MSD end stop mount variable height.stl
16.8 x 13.8 x 33.1

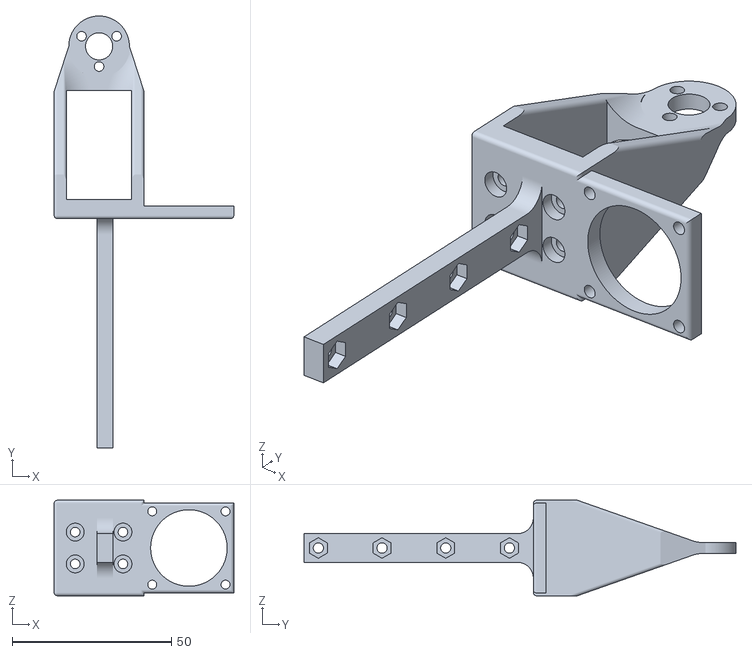
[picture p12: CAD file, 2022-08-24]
Experiments/Hardware/CRM advanced modules/Prints/Sample extraction storage/Horizontal MSD movement carriage- Nema11 Motor outside frame.stl
56.4 x 135.6 x 30.0

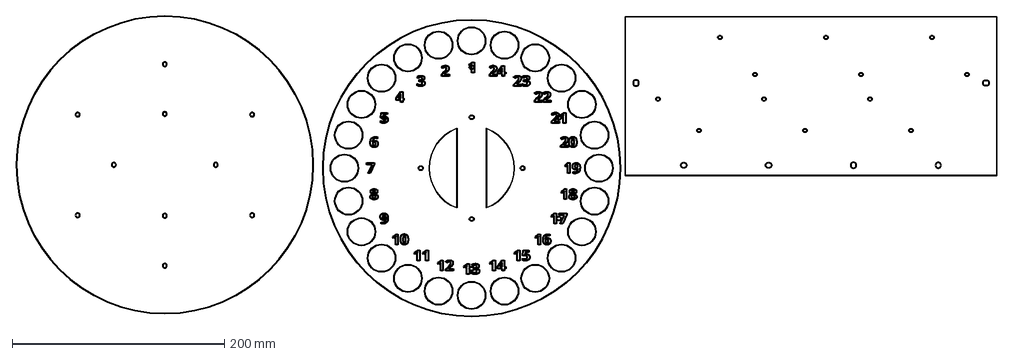
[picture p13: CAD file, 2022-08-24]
Experiments/Hardware/Modular wheel/Cuts/Vial tray and arduino mount 4mm.dxf
924.4 x 283.0 mm

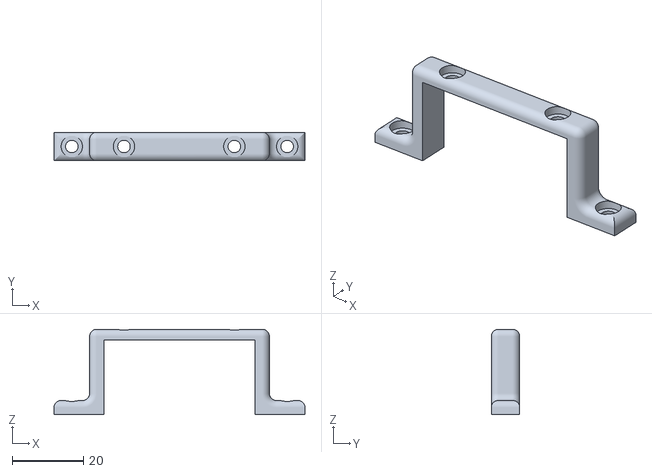
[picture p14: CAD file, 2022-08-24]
Experiments/Hardware/Modular wheel/Prints/Base plate parts/Nema 17 Motor securing brackets.stl
70.5 x 8.00 x 24.0

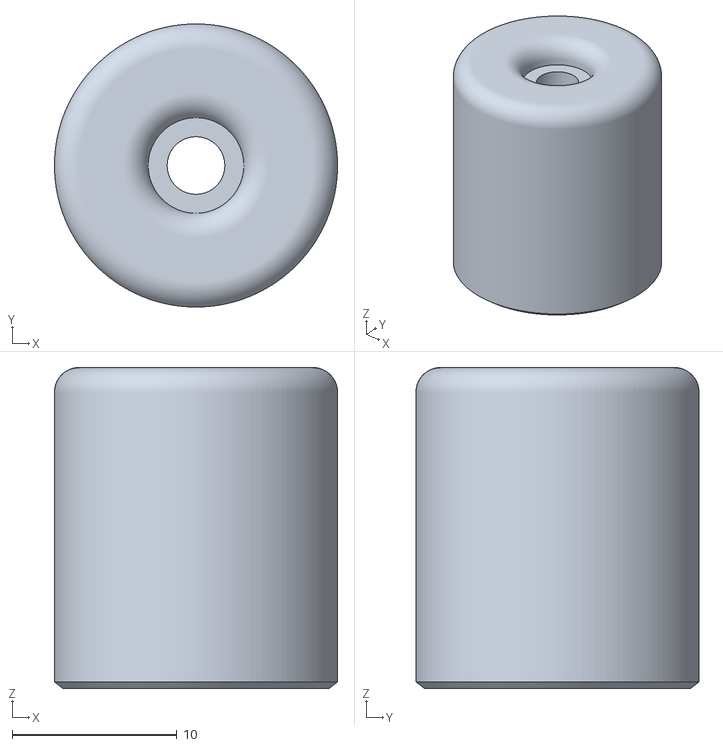
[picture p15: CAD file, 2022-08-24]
Experiments/Hardware/Modular wheel/Prints/Dispensing unit/Dispensing module 7 1-16 tubes securing piece.stl
17.2 x 17.2 x 19.5

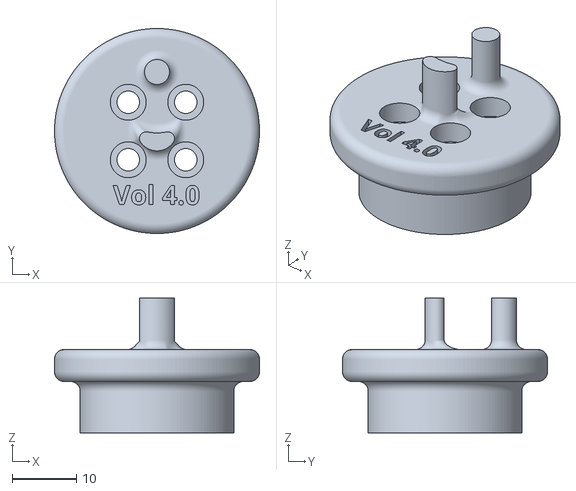
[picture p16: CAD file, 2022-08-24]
Experiments/Hardware/Modular wheel/Prints/Drive wheel/MWP/Drive wheel Nanobot 4.0.stl
32.0 x 32.0 x 21.0

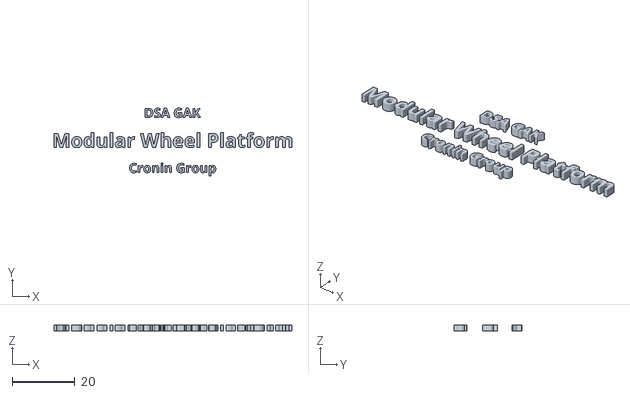
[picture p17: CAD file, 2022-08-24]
Experiments/Hardware/Modular wheel/Prints/Driven wheel/Driven wheel Modular wheel platform- Inlay.stl
75.6 x 21.5 x 2.00

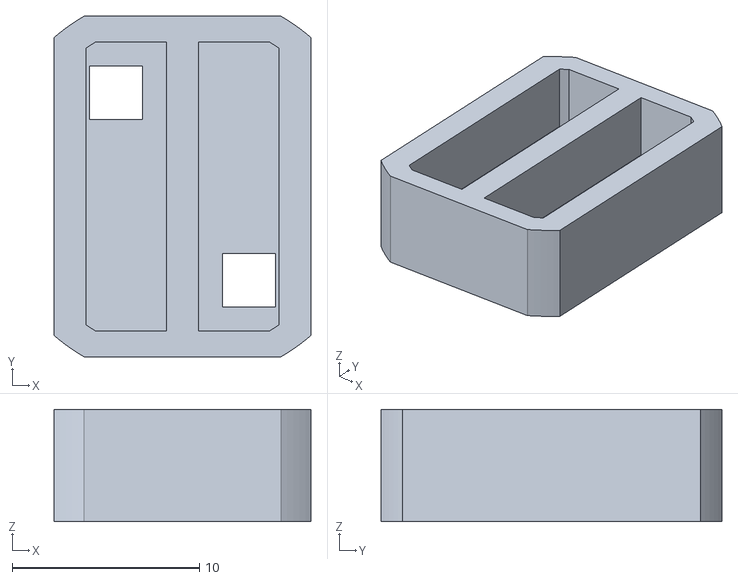
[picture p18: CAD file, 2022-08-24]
Experiments/Hardware/Modular wheel/Prints/Stirring magnet housing/Magnet housing 2.2kg pull rectangular.stl
13.7 x 18.2 x 6.00

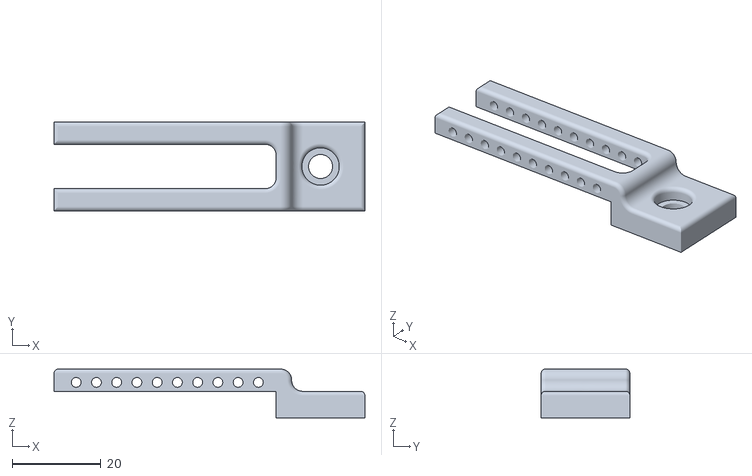
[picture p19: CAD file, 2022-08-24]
Experiments/Hardware/Modular wheel/Prints/Tube holder/Raw tube dispensing module tube guide.stl
70.0 x 20.0 x 11.0

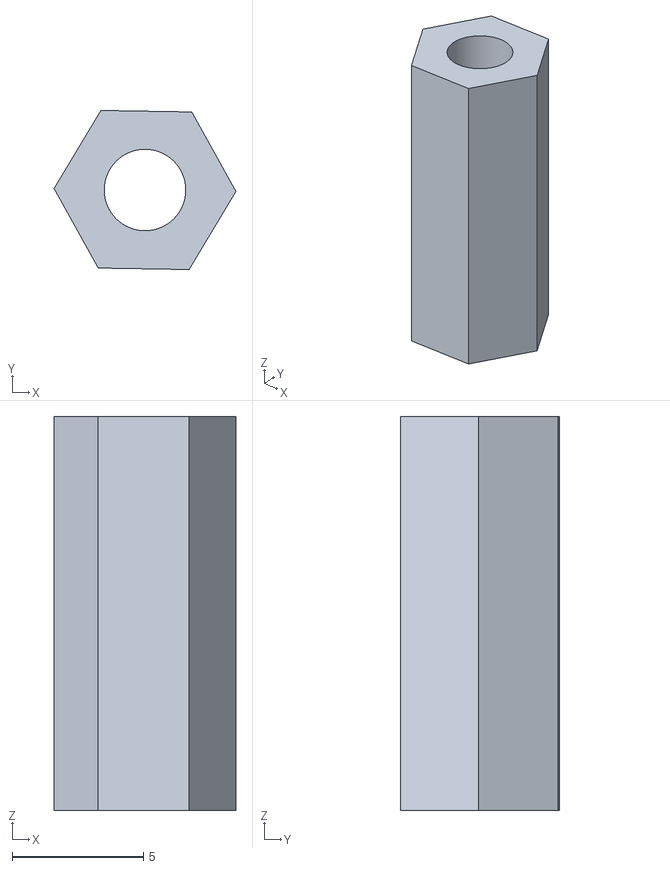
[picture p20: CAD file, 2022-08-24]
Experiments/Hardware/Modular wheel/Prints/Vial tray/Hex spacer.stl
6.93 x 6.06 x 15.0

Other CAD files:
Experiments/Hardware/CRM advanced modules/Cuts/Wash and storage stations/Wash station fixed acrylic - Mid vial cut.dxf
Experiments/Hardware/Platform box/Cuts/Box base parts - Top left.dxf
Experiments/Hardware/Spectroscopic suite/Cuts/Flow cell balcony base plate.dxf
Experiments/Hardware/Spectroscopic suite/Prints/Spectrometer shelf mount right.stl
Experiments/Hardware/CRM advanced modules/Cuts/Wash and storage stations/Fixed wash station 3 levels of vial holder cuts.dxf
Experiments/Hardware/CRM advanced modules/Cuts/Wash and storage stations/Wash station fixed acrylic - Above vial with tube guides.dxf
Experiments/Hardware/CRM advanced modules/Cuts/Wash and storage stations/Wash station fixed acrylic- Under vial cut.dxf
Experiments/Hardware/CRM advanced modules/Prints/Sample extraction analysis/Carriage to lead screw piece.stl
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

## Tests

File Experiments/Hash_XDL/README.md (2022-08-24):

# The Digital Signatures of Nanoparticles using XDL
This folder contains the XDL file of the synthesis of six nanoparticles. The corresponding code to convert them into a unique Hash representation is also shown. 
#### Example code
```python
from xdl import XDL
import hashlib
import numpy as np

def sort_reagent_name(xdl):
    """
    Sort the reagents of XDL according to their names
    Args:
        xdl:XDL objects
    Returns:
        xdl:Updated XDL obeject
    """
    xdl_json = xdl.as_json()
    indexes = np.argsort([xdl_json['reagents'][i]['name'] for i in range(len(xdl_json['reagents']))])
    xdl_json['reagents'] = [xdl_json['reagents'][index] for index in indexes]
    return XDL(xdl_json)

# Hash the initial seed
test_xdl = XDL("NP_seed.xdl")
test_xdl = sort_reagent_name(test_xdl)
xdl_str = test_xdl.as_string()
hash_value = hashlib.sha256((xdl_str+'True').encode('UTF-8')).hexdigest()
# print(xdl_str)
print(hash_value)

```

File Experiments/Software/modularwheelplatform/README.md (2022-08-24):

# Modular Wheel Platform Guide

wheel
This repository provides all of the software and harware build files and instructions necessary for creating your own version of a Modular Wheel Platform (MWP).  
The MWP is multi-reaction dispensing station, enabling a far higher reaction throughput compared to conventional benchwork. With this system, multiple reactions can be conducted simultaneously with minimal downtime - determined by dispensing rate and wheel size. The system can incorporate several different types of attachable modules for probe analysis, reaction-reaction transfer and sample extraction. Stand alone modules for heating/stirring, filtration and storage are also included in this repository. 

# Useful Links

* [Overview of Platform Structure](docs/PlatformOverview.md)
* [Firmware Setup](docs/CommandFirmware.md)

# Software Requirements

* Python 3 ([Linux](http://docs.python-guide.org/en/latest/starting/install3/linux/) / [Windows](https://www.python.org/downloads/release/python-363/))

* [Arduino IDE](https://www.arduino.cc/en/Main/Software)
* [Commanduino](https://github.com/croningp/commanduino)
* [Arduino Command Handler](https://github.com/croningp/Arduino-CommandHandler)
* [Arduino Command Tools](https://github.com/croningp/Arduino-CommandTools)

## Optional

* [PyCont](https://github.com/croningp/pycont) (If using Tricontinent Pumps)

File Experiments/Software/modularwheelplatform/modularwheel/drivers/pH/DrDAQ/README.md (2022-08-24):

# Dr DAQ pH Device

DrDAQ

This is the README available on the [PicoTech GitHub](https://github.com/picotech/picosdk-python-wrappers/blob/master/README.md)

Contains installation instructions and all the necessary information. Link to PDF manual [here](https://www.picotech.com/download/datasheets/usbdrdaq-data-logger-programmers-guide.pdf).

---

Welcome to the PicoSDK for Python. It allows you to control PicoScope devices in your own Python programs.

## Getting started

To use this code you will need to install the PicoSDK C libraries.

### Microsoft Windows

Please visit [our Downloads page](https://www.picotech.com/downloads) to download the 32-bit or 64-bit PicoSDK C Libraries for Windows. 
Please take care to match the "bitness" of your python to the PicoSDK.

### Linux

Follow the instructions from our [Linux Software & Drivers for Oscilloscopes and Data Loggers page](https://www.picotech.com/downloads/linux) 
to install the required driver packages for your product.

### macOS

macOS users should install PicoScope Beta for macOS, and then may find this [forum post](https://www.picotech.com/support/topic22221.html) helpful for installing the C 
libraries.

## Installing the python driver bindings

A `distutils` installer is provided. After you have installed the PicoSDK
driver package (see above), the Python installer can be used as follows:

    python setup.py install

On macOS and Linux you will either need to use `sudo` with this command, to
install into the system folders, or to install for the current user only you
can use:

    python setup.py install --user

Within python, the library for `import` is called `picosdk`.

## Compatibility

This code is written to be compatible with both python 2.7 and python 3 (any version).

If you find a compatibility problem please raise an [Issue](https://www.picotech.com/tech-support), listing all the versions you can find (python, numpy, 
picosdk commit hash, etc.) and your error message(s).

## C interface

You can access C driver functions directly (ctypes calls) by their original C name, following the [Programmer's
Guides](https://github.com/picotech/picosdk-python-wrappers#programmers-guides) exactly. Examples are provided in the folders like `psX000[a]Examples/`.

### Programmer's Guides

You can download Programmer's Guides providing a description of the API functions for the relevant PicoScope or 
PicoLog driver from our [Documentation page](https://www.picotech.com/library/documentation).

## Python interface

We are in the process of adding Pythonic wrappers around the C functions. If we haven't got to your feature yet or your device is listed as one of the [unsupported models](https://github.com/picotech/picosdk-python-wrappers#unsupported-models),
let us know that you're waiting in an [Issue](https://www.picotech.com/tech-support)

### Unsupported models

The following drivers and devices are not yet supported:

* `plcm3` - PicoLog CM3 Current Data Logger
* `ps3000` - PicoScope 3204, 3205, 3206, 3223, 3224, 3423 & 3423
* `usbdrdaq` - DrDAQ Data Logger
* `usbpt104` - PT-104 Platinum Resistance Data Logger

### Dependencies

As well as depending on the C libraries, the Pythonic wrappers use some python libraries like `numpy`. Many of the
examples scripts also use the `matplotlib` plotting library. You can install these dependencies with pip as follows:

    pip install -r requirements.txt
    pip install -r requirements-for-examples.txt

### Driver-agnostic examples

The `anyScopeExamples` folder contains examples in pure python which do the same thing as the C-style examples, but
in a driver-generic way.

### Python Classes

#### Library

`picosdk.library.Library` contains a base class for each of the driver classes. It does the job of translating python
types into C ones, and back again, and some unit conversions to get rid of nano, micro and milli-style prefixes. It also
handles any differences in programming API between PicoScope driver versions.

#### Device

`picosdk.device.Device` contains the concrete class which represents a PicoScope with a valid handle. It caches some
information about the device state, like the currently selected voltage ranges of the channels.

It is implemented in terms of the Library class' public interface, and deals almost entirely with python types. The
main exception is its handling of numpy arrays - it (knowing the voltage ranges) is responsible for converting the raw
ADC counts that the driver uses for amplitude into physical units.

## Testing this code

Check which device driver your device uses, and check the constants at the top of test/test_helpers.py to enable the 
relevant drivers for connected-device tests. (most tests use this).

To check which driver your device uses, you can use `picosdk.discover`:

    from picosdk.discover import find_all_units
    
    scopes = find_all_units()
    
    for scope in scopes:
        print(scope.info)
        scope.close()

You should then configure test/test_helpers.py's list of connected devices, so it can run all the tests we have
on your device.

To run the unit tests, you will need to install nose (e.g. `pip install nose`.) Then, run `nosetests` in the root of 
the repo. 

## Obtaining support

Please visit our [Support page](https://www.picotech.com/tech-support) to contact us directly or visit our [Test and Measurement Forum](https://www.picotech.com/support/forum17.html) to post questions.

## Copyright and licensing

See [LICENSE.md](https://github.com/picotech/picosdk-python-wrappers/blob/master/LICENSE.md) for license terms. 

*PicoScope*, *PicoLog* and *PicoSDK* are registered trademarks of Pico Technology Ltd. 

*Windows* is a registered trademark of Microsoft Corporation. 

*macOS* is a registered trademark of Apple Inc. 

*Linux* is the registered trademark of Linus Torvalds in the U.S. and other countries.

Copyright © 2018-2019 Pico Technology Ltd. All rights reserved.

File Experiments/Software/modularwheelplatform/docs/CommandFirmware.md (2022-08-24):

# Firmware Setup For Commanduino
The following is a description of how to set up the Arduino firmware for use with Commanduino.

## Installation
Clone the following repositories and follow the basic set up instructions within (Works with Windows/Linux)
* [Arduino Command Handler](https://github.com/croningp/Arduino-CommandHandler)
* [Arduino Command Tools](https://github.com/croningp/Arduino-CommandTools)

## Basic Setup

* Include the Command Handler and Command Manager at the top of your file and create a CommandManager instance

```C++
#include <CommandHandler.h>
#include <CommandManager.h>
CommandManager cmdMgr;
```

* Include the basic Arduino devices you will be using e.g. AccelSteppers, Servos, etc.

```C++
#include <AccelStepper.h>
#include <LinearAccelStepperActuator.h>

/* Additional Modules if necessary */
```

* Next, include the "Command" version of all your included devices from above

```C++
#include <CommandAccelStepper.h>
#include <CommandLinearAccelStepperActuator.h>
```

* Now instantiate the Arduino device objects and their Command equivalents
    * Note: The numbers are pins and these may change depending on your setup  

```C++
AccelStepper stepper1(AccelStepper::DRIVER, 54, 55);
CommandLinearAccelStepperActuator cmdStepper(stepper1, 3, 38);

/* Additional Object creation */
```

## Setup Function

Within the setup function, we use the created CommandDevice objects and add them to the manager. Each object is given a unique ID that the user specifies.

```C++
void setup() {
    /* Here, "drive_wheel" is the unique ID */
    cmdStepper.registerToCommandManager(cmdMgr, "drive_wheel");

    /* Register the remaining devices in a similar fashion */
}
```

## Loop Function

The loop function only contains single call for the manager to update. Nothing else is required here.

```C++
void loop() {
    cmdMgr.update();
}
```

# Pin Mappings

One of the most common uses of Commanduino is controlling stepper motors for movement, pumps, etc. To be able to use multiple stepper motors on a single Arduino board, a RAMPS shield is used, giving access to 5 possible motor locations and a collection of pins for other devices. Below is a list of pin mappings for using multiple stepper motors on a single RAMPS shield.

```C++
X_STEP_PIN         54
X_DIR_PIN          55
X_ENABLE_PIN       38

Y_STEP_PIN         60
Y_DIR_PIN          61
Y_ENABLE_PIN       56

Z_STEP_PIN         46
Z_DIR_PIN          48
Z_ENABLE_PIN       62

E0_STEP_PIN         26
E0_DIR_PIN          28
E0_ENABLE_PIN       24

E1_STEP_PIN         36
E1_DIR_PIN          34
E1_ENABLE_PIN       30

X_MIN_PIN          3
X_MAX_PIN          2
Y_MIN_PIN          14
Y_MAX_PIN          15
Z_MIN_PIN          18
Z_MAX_PIN          19
```

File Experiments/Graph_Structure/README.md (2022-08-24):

# Directed Graph Structure of Multistep Synthesis of Au NPs
Create synthesis,reaction and hardware graph of a complex nanostructure network with dedicated synthetic conditions.

## Example code
One example is available [here](Graph_Generator.ipynb). 
The synthetic conditions of different nanostructures should be defined in [exp_info.json](exp_info.json).

After running the example code, [experiments](Experiment) and [three graphs](Graphs) can be generated. 

The experimental data should be copies to the [custom folder](../Software/Graph_Experiment/data/custom) in the software control. Also, we recorded the operations to reach certain pHs when finding the nanostructures in the second batch and used them in reproducing them. So "pH_operation.json" files were added in the same folder. 

Copy all the content in [Graphs](Graphs) to the [experiments](../Software/Graph_Experiment/experiments) folder in Graph_Experiment and run the [Python script](../Software/Graph_Experiment/experiments/basic.py) will synthesize the six nanostructures.

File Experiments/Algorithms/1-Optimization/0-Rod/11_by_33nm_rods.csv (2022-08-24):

6.105442047119140625e-01
5.973721742630004883e-01
5.832922458648681641e-01
5.694920420646667480e-01
5.588885545730590820e-01
5.490779876708984375e-01
5.372279882431030273e-01
5.269455909729003906e-01
5.243491530418395996e-01
5.344480872154235840e-01
5.590460300445556641e-01
5.839552879333496094e-01
5.819414258003234863e-01
5.581025481224060059e-01
5.341807007789611816e-01
5.020827651023864746e-01
4.487155973911285400e-01
3.792653977870941162e-01
3.145742416381835938e-01
2.701345682144165039e-01
2.435370087623596191e-01
2.273098528385162354e-01
2.203425467014312744e-01
2.188171446323394775e-01
2.218311876058578491e-01
2.290873080492019653e-01
2.461492568254470825e-01
2.804217040538787842e-01
3.385461270809173584e-01
4.306041896343231201e-01
5.745061039924621582e-01
8.013571500778198242e-01
1.178576946258544922e+00
1.866983652114868164e+00
3.203244209289550781e+00
5.613687515258789062e+00
7.482892990112304688e+00
5.681311607360839844e+00
3.303880214691162109e+00
1.953474640846252441e+00
1.249037146568298340e+00
8.580703139305114746e-01
6.220608353614807129e-01
4.679524898529052734e-01
3.622003495693206787e-01
2.875717282295227051e-01
2.337730377912521362e-01
1.945587843656539917e-01
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

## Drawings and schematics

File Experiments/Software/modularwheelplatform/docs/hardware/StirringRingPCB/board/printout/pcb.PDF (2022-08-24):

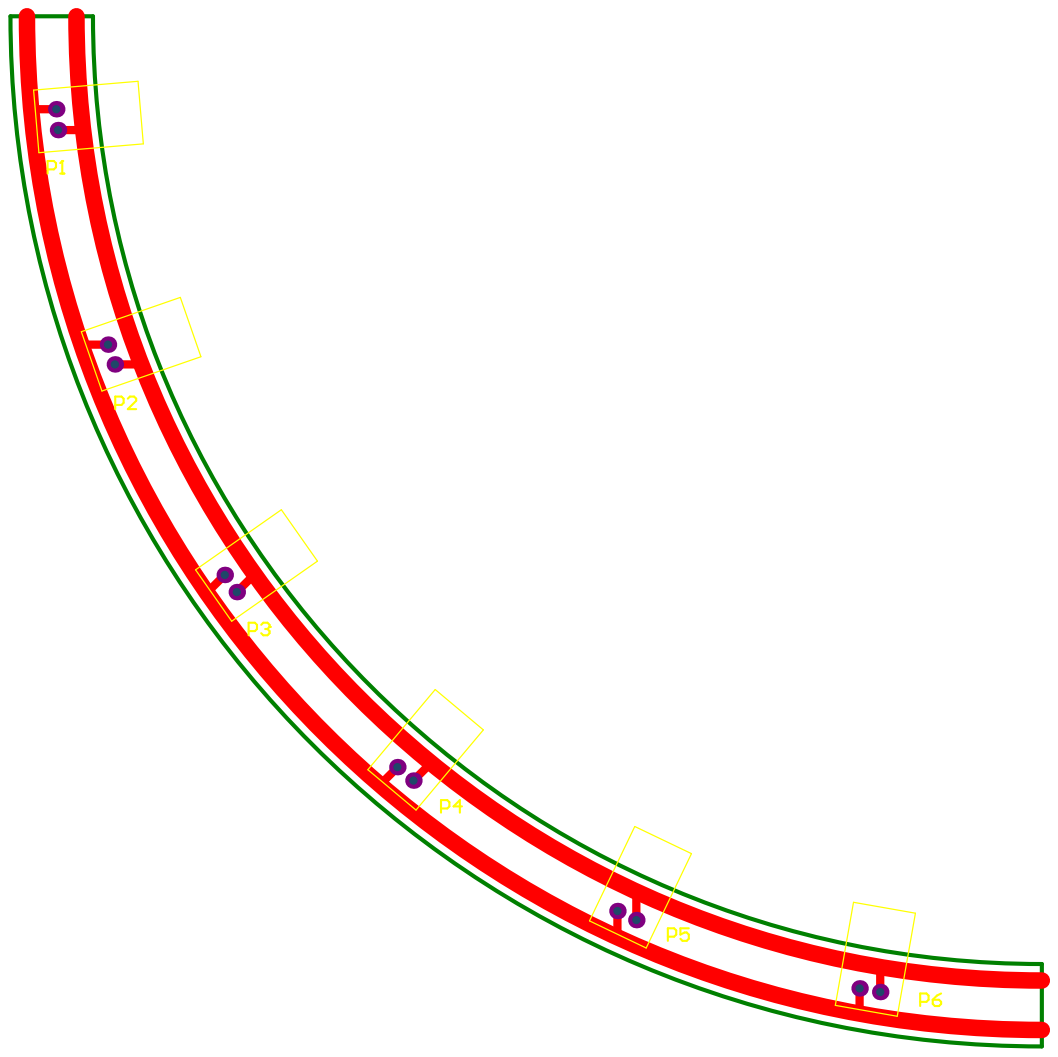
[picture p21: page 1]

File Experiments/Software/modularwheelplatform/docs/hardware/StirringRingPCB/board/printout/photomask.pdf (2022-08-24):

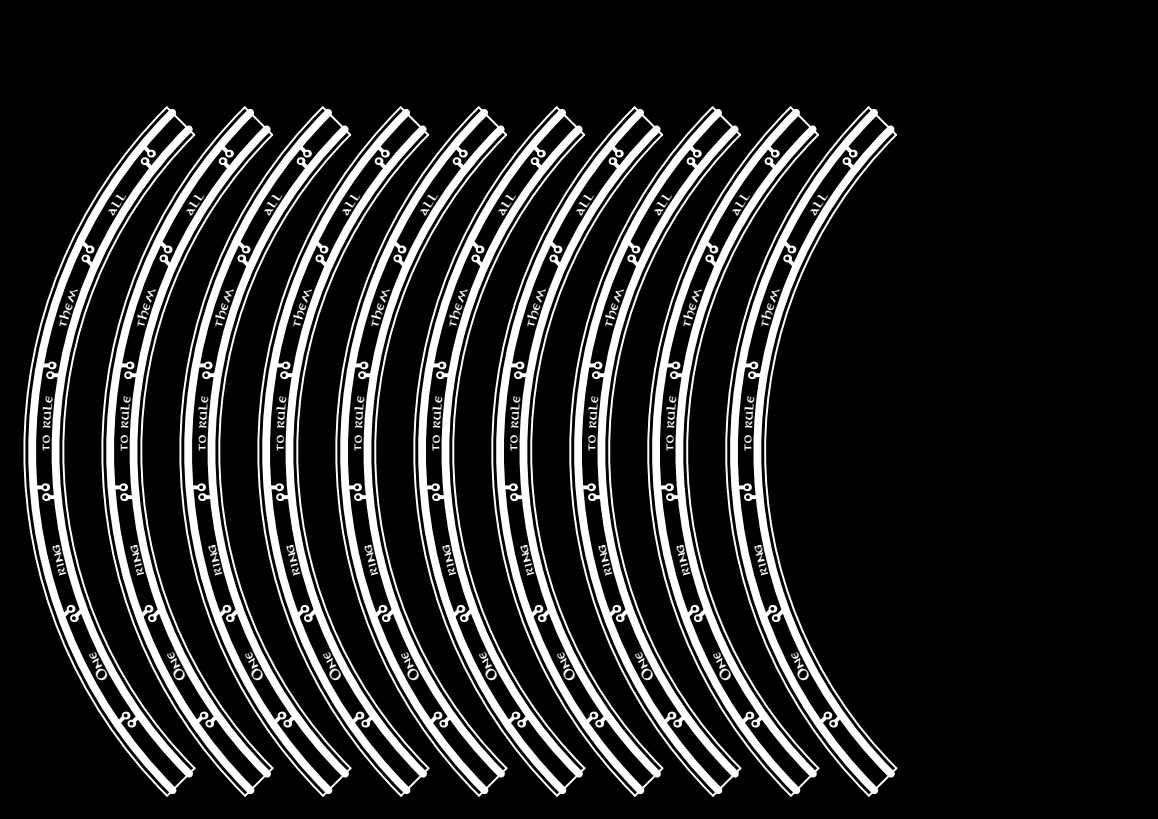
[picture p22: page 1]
One; them; all

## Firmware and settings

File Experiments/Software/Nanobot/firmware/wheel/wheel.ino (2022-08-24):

/**
#define X_STEP_PIN         54
#define X_DIR_PIN          55
#define X_ENABLE_PIN       38

#define Y_STEP_PIN         60
#define Y_DIR_PIN          61
#define Y_ENABLE_PIN       56

#define Z_STEP_PIN         46
#define Z_DIR_PIN          48
#define Z_ENABLE_PIN       62

#define E0_STEP_PIN         26
#define E0_DIR_PIN          28
#define E0_ENABLE_PIN       24

#define E1_STEP_PIN         36
#define E1_DIR_PIN          34
#define E1_ENABLE_PIN       30

 #define X_MIN_PIN          3
 #define X_MAX_PIN          2
 #define Y_MIN_PIN          14
 #define Y_MAX_PIN          15
 #define Z_MIN_PIN          18
 #define Z_MAX_PIN          19
 **/

#include <CommandHandler.h>
#include <CommandManager.h>
CommandManager cmdMgr;

/* Include the base files needed such as Accel Stepper, Servo etc */
#include <AccelStepper.h>
#include <LinearAccelStepperActuator.h>

/* Include the "Command" version of the above */
#include <CommandAccelStepper.h>
#include <CommandLinearAccelStepperActuator.h>

//PWM for fans
#include <CommandAnalogWrite.h>

// Laser Power Control
#include <CommandDigitalWrite.h>


/* Set up the base objects and Command objects */
AccelStepper stepperX(AccelStepper::DRIVER, 54, 55);
CommandLinearAccelStepperActuator X(stepperX, 3, 38);

AccelStepper stepperY(AccelStepper::DRIVER, 60, 61);
CommandLinearAccelStepperActuator Y(stepperY, 14, 56);

AccelStepper stepperZ(AccelStepper::DRIVER, 46, 48);
CommandLinearAccelStepperActuator Z(stepperZ, 18, 62);

AccelStepper stepperE0(AccelStepper::DRIVER, 26, 28);
CommandLinearAccelStepperActuator E0(stepperE0, 2, 24);

AccelStepper stepperE1(AccelStepper::DRIVER, 36, 34);
CommandLinearAccelStepperActuator E1(stepperE1, 15, 30);


//PWM
CommandAnalogWrite ring(8);
CommandAnalogWrite wash(9);


/* Do this for the rest of your devices */

void setup() {
    Serial.begin(115200); // Always 115200

    /* Register devices to the command manager */
    X.registerToCommandManager(cmdMgr, "X"); 
    Y.registerToCommandManager(cmdMgr, "Y");
    Z.registerToCommandManager(cmdMgr, "Z");
    E0.registerToCommandManager(cmdMgr, "E0"); 
    E1.registerToCommandManager(cmdMgr, "E1");
    
    /* Do this for the rest of your devices */
    ring.registerToCommandManager(cmdMgr, "ring");
    wash.registerToCommandManager(cmdMgr, "wash");

    cmdMgr.init();
}

void loop() {
    cmdMgr.update();
    /* Nothing else needed here */
}
